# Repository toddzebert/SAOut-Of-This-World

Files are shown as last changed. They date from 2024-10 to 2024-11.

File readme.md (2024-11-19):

# SAOut Of This World

Originally intended for the [2024 Supercon SAO Contest] (https://hackaday.com/tag/2024-supercon-sao-contest/) but we missed the deadline. Wha wha. We'll be introducing it at Supercon 2024 in early November in Pasadena, CA.

A koppanyh and Todd Zebert production. 
 
Copyright (c) 2024 koppanyh & Todd Zebert, under a modified MIT license.

Kop handled the PCB design and art, with a bit of input from Todd, while Todd was working on the code bouncing ideas off of Kop.

## Features

Besides being out of this world in design and fairly LED-y, it works as an i2c target device to both select different "effects" or assume complete control of the 5 LEDs and 16 WS2812s. Two LEDs are wired to in a special "sensing" circuit. It also features two buttons.

## Usage

The left button sequences between "Effects" for the Upper Trim (the 5 WS2812's in the middle), while the right button sequences between Effects for the Lower Trim (WS2812's at the bottom).

A long press on the left button will enter "brightness control mode" - the left eye will go into a rapid red flashing to indicate such. Subsequent regular (short) button presses on left or right, will decrease or increase, respectively, brightness. Use a left long press to return to normal mode.

## Todo's

* Create hackaday.io project 
* see [Firmware readme](firmware/readme.md)

## Board Previews.

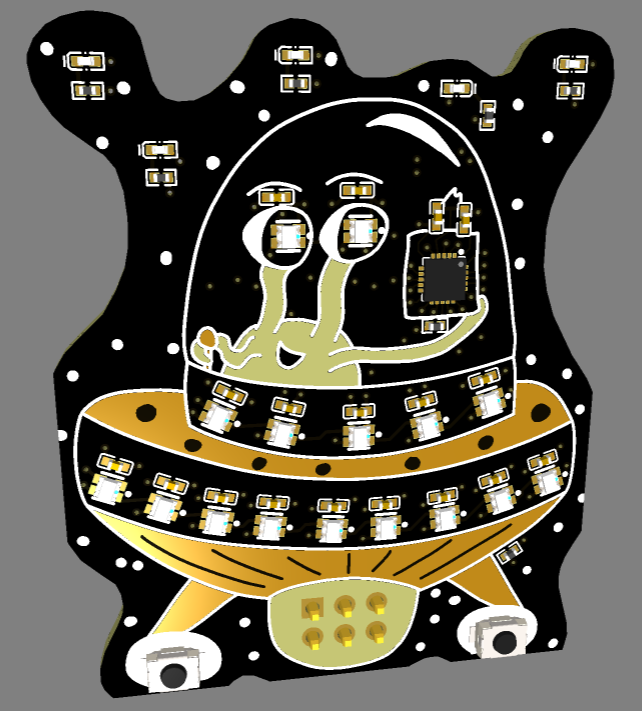
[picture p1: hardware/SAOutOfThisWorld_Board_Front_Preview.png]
SAOut Of This World Front Preview

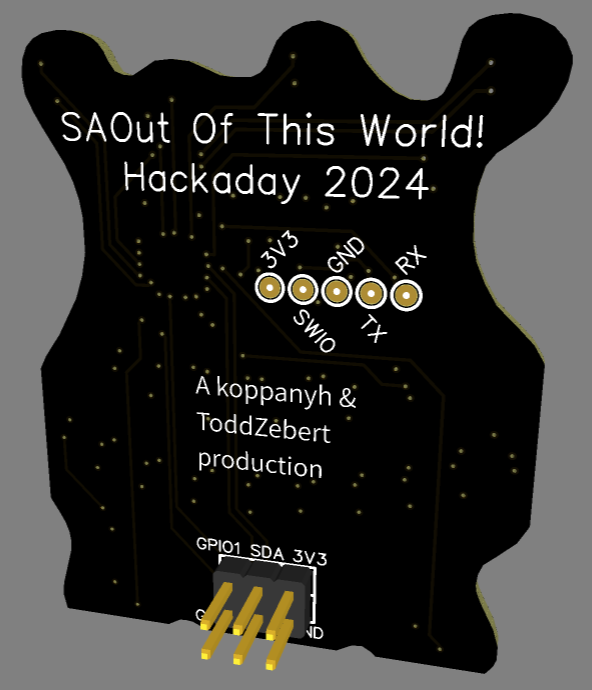
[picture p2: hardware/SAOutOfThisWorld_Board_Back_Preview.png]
SAOut Of This World Back Preview


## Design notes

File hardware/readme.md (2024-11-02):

# Hardware

## Ports, Usages, Pins, etc.

| Port | Usage | Pin | Notes |
|---|---|-----|---|
| NRST | GND |  1  | |
| PA1 | SenseLED1+ |  2  | *A1 |
| PA2 | GLED3 |  3  | *A0 |
| VSS | GND |  4  | |
| PD0 | GLED2 |  5  | *Non-A |
| VDD | VCC |  6  | |
| PC0 | GLED1 |  7  | *Non-A |
| SDA | SDA |  8  | PC1 |
| SCL | SCL |  9  | PC2 |
| PC3 | Button1 | 10  | to GND, Pull-up |
| PC4 | Button2 | 11  | to GND, Pull-up |
| PC5 | SAO GPIO2  | 12  | |
| MOSI | Neopixel | 13  | PC6 |
| PC7 | SAO GPIO1  | 14  | |
| SWIO | SWIO | 15  | PD1, Programer, exp. pad |
| PD2 | SenseLED2- | 16  | *A3 |
| PD3 | SenseLED2+ | 17  | *A4 |
| PD4 | SenseLED1- | 18  | *A7 |
| UTX | UTX | 19  | PD5, USART, exposed pad  |
| URX | URX | 20  | PD6, USART, exposed pad  |
| VSS | GND | 21  | |

## Sense LEDs

Two LEDs are both sunk and sourced by the MCU so it can run both in forward and reverse bias (sensing) modes. 

## CH32 Product line part number notes
In case you were curious, Ex: CH32V003F4U6

- CH32 = product line.
- V = QingKe RISC-V-based
- 0 = QingKe V2 core (no FP)
- 03 = General Purpose
- F = 20 pins
- 4 = 16 Kbytes of Flash memory 
- P/U = TSSOP/QFN respectively
- 6 = -40℃～85℃ (industrial-grade)

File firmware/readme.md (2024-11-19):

# Firmware for SAOut Of This World

## Setup
1) Install VSCode
2) Install the PlatformIO extension in VSCode
3) Clone the [ch32v003fun](https://github.com/cnlohr/ch32v003fun) repo
4) Follow the [installation](https://github.com/cnlohr/ch32v003fun/wiki/Installation) guide
5) Open it with PlatformIO and let it set up
6) Open the SAOut Of This World firmware project with PlatformIO
7) Let it set up, then click Build to see if it worked

# Description

At its core, its a synchronous finite state machine; it's not (directly) event-driven, because events are "buffered" into the synchronous tock of the main loop. It more or less follows the [UML state machine](https://en.wikipedia.org/wiki/UML_state_machine). It's written in straight C.

It uses the [ch32v003fun](https://github.com/cnlohr/ch32v003fun) "environment" to avoid the manufacturer's weighty HAL/EVT; the community around it has been very helpful. We also use PlatformIO to build the project.

Conceptually, initially an init Event is passed to each Thing. Then there's the main loop, which communicates with Things. There are two types of Things: input and output. Output Things (like Stars,Eyes, Trim) are associated with and communicate with Effects (like Twinkle, Blink, Rotate). Input Things (like Buttons, GPIO) do not have associated Effects.

Effects each have a timer, based on tocks, associated with a Thing. When the timer expires, a Run Event is passed to each Thing which in turn passes on the event to the Effect. Other input events are passed similarly via the main loop.

Another way of thinking about it is kinda like PubSub, but Things don't have to "subscribe", we "publish" all events to all Things (then passed on to Effects). Currently, Effects return a "dirty" flag, which is then returned by the corresponding Thing, to alert the main loop that the WS2812s need to be updated.

Other input events include i2c writes, (SAO) GPIO inputs, buttons and the "sense" LEDs. Most are "polled" with the exception of the i2c writes (handled by an ISR). Polled Things return an Event, to be processed in the main loop. The i2c is unique and isn't really a Thing; it "sends" Events by setting a "Global Event" var which again, is processed in the main loop. 

While both Things and Effects maintain there own UML "action" state (ENTER, GO, EXIT, etc), as do "output" Things, but so far there's no need for "output" Things to do so. Things and Effects also maintain their own internal state, as needed.

The next most important concept is the "registry". Because this SAO is meant to be an i2c target, all the settings and outputs are stored in the registry. The i2c library modifies the registry directly when it receives a write. Things and Effects depend on both reading and writing to the registry. Any i2c controller can switch Effect "modes", settings, or even control the LEDs and WS2812s directly using the "Raw" Effect.

For Stars, the 8bit value is passed through a gamma map table, then its reduced to 6 bits for the LED soft PWM.

The MCU is the CH32V003F4U6 (QFN-20) chip, with 2 buttons, 16 WS2812s (in one channel) and five (soft PWM)LEDs, two of which are wired special - see the hardware readme.

When tested during supercon 2024, it was pulling high 30's to mid 40's ma.

## Tock

`SysClick` is used to create a synchronous 1ms "tock". The main loop runs on the tocks.

## i2c Use
@todo
* I2C_ADDRESS 0x09

## Libraries (/lib)
* Color Utilities
* i2c_slave
  * Modified from example - thanks [true] - to:
    * better handle errors, especially stop.
    * Not call callbacks when i2c IDs don't match.
    * Increase priority.
* rand
* ws2812b_dma_spi_led_driver

## TODO & Progress

* [In progress] Finish & test i2c. Probably need a "dirty" reg entry - nope, write callback can determine.
* [Emit done, queue added, thing "listeners" some done] Things' (input) events and actions.
* Enhance and add Effects (perhaps "pallets" in each effect>)
* Review GH Issue.
* [Hold] Sense LEDs

## Change Log

* [Done] Global "mode" visual indications, perhaps eyes?
* [Done] brightness control.
* [Done] Fix Comet effect
* [Done] make Twinkle fade-in/fade-out.
* [Done] Buttons
* [Done] Events base code
* [Done] Fix "PA" GPIO pins - thanks Discord
* [Done] reduce GPIO speeds
* [Done] fix i2c crashing - thanks [true]
* [Done] Make LEDs (soft) PWM - thanks [true]
  
## Future ideas

* The mismatch of the length of `enum Things_t` and arrays such as `reg_thing_start[]` could be an issue in the future.
* Right now Things and Effects return `dirty` to alert the main loop that the WS' need to be updated, and timing intervals (delays) are set in a global var. I'd like to uncouple that so they return a struct with both dirty and delay, and maybe more. I want to avoid putting too much on the stack though, although I suspect the call stack is never more than a few calls deep: Main Loop, Thing, Effect handler, Effect State handler, and perhaps a helper routine. There's no recursion.
* Twinkle effect: add normally on and normally off modes.
* Add the "CC3K" effect.
* Move i2c stuff from main to its own file, and DRY out `main()` including the main loop.

## CH32V003FUN Platform Notes

* To get a random binary: `rnd_fun(0, 1) & 0x01)`
* To get a 0-255 randomly: `(uint8_t)rnd_fun(0, 1)`
* It does not support `malloc`.
* For best RISC performance, focus on 0's in loops/counters.
* The i2c_slave/src/i2c_slave.h is modified from the fun example's version to clear stop condition on error, and increase IRQ priority.
* Do not use `Delay_Ms()` as it is incompatible with 

## Thanks.
Special thanks to cnlohr for the [ch32v003fun](https://github.com/cnlohr/ch32v003fun) project,
and all the helpful people on his Discord server. And to [true] at the Hackaday Supercon 2024.

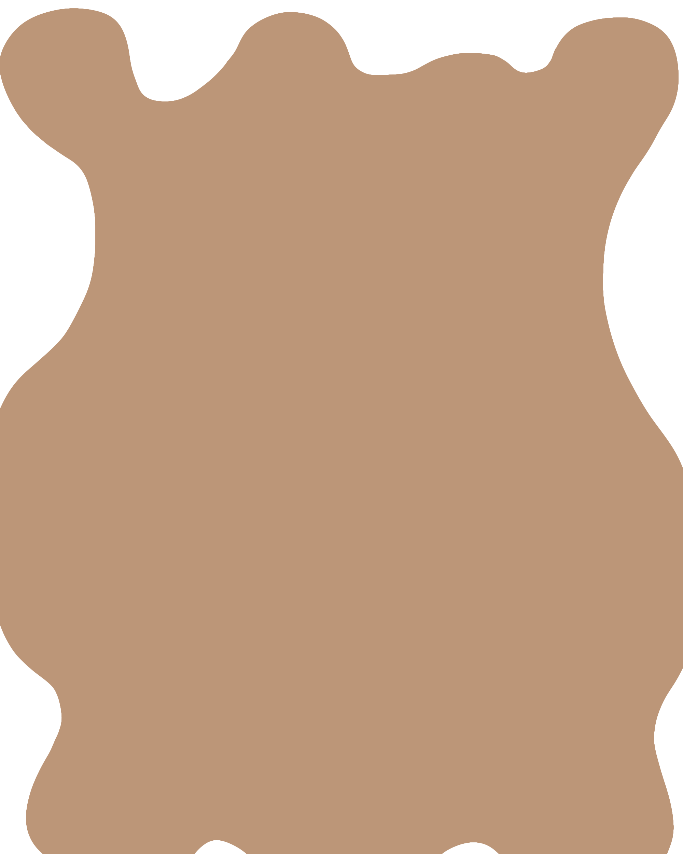
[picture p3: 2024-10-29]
hardware/pcb_layers/board.png

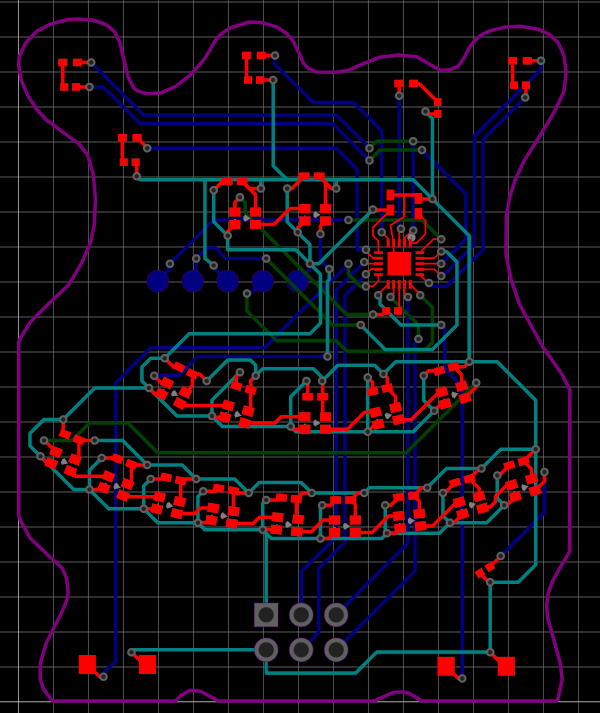
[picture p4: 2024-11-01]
hardware/SAOutOfThisWorld_Board_Traces.png

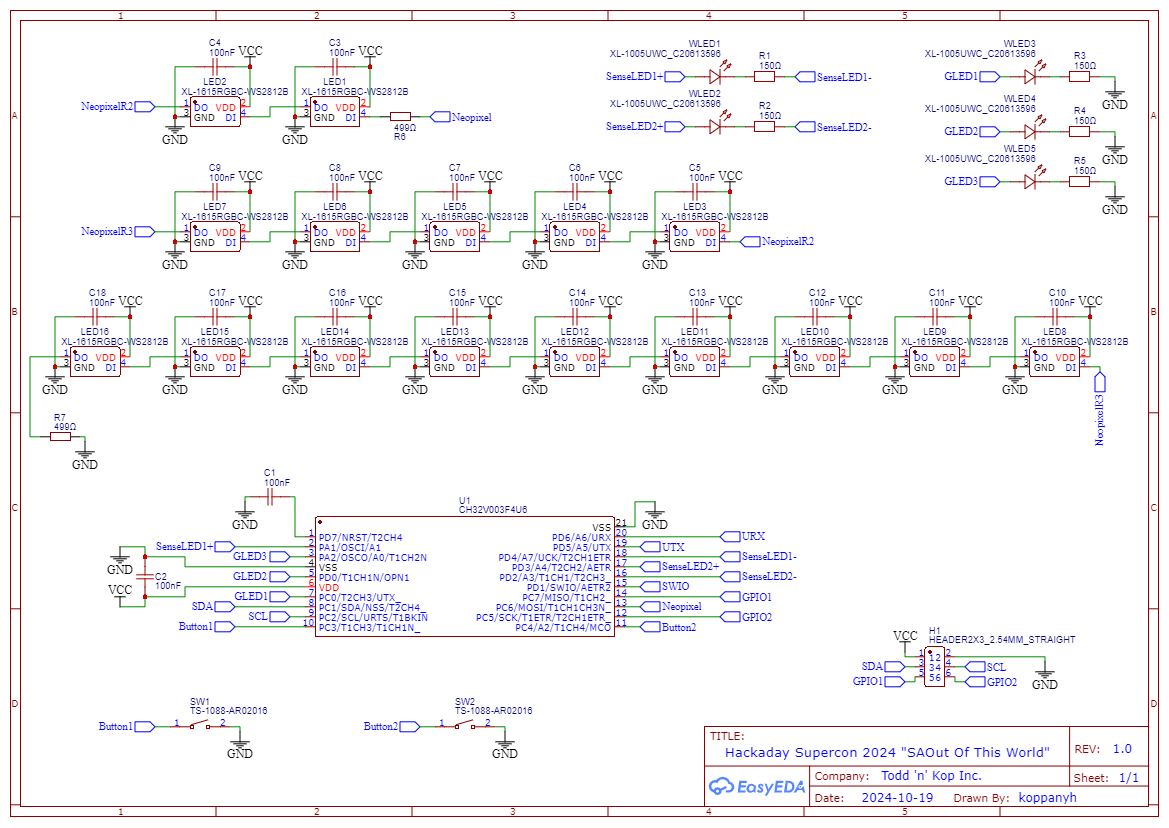
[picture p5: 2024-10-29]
hardware/Schematic_HD2024SAO.png

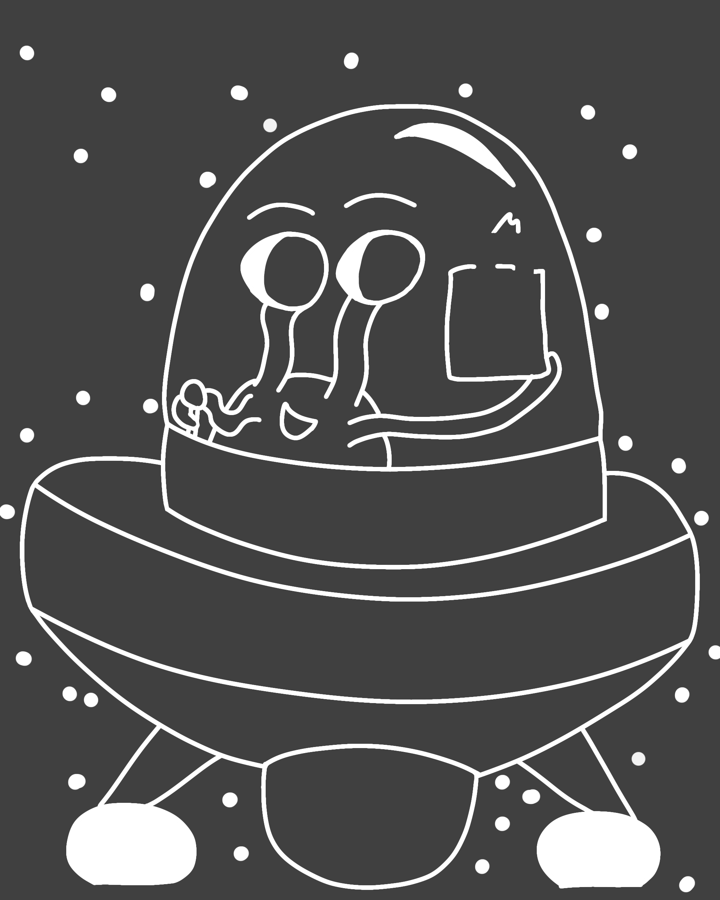
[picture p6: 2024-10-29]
hardware/pcb_layers/silkscreen.png

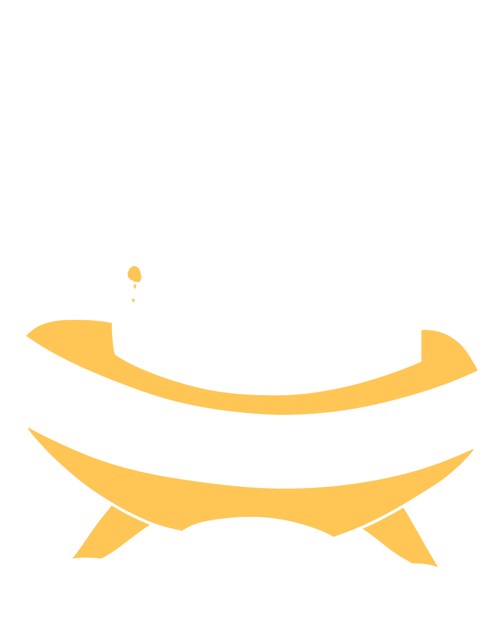
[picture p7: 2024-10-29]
hardware/pcb_layers/copper.png

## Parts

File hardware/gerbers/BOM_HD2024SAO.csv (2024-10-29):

ID | Name | Designator | Footprint | Quantity | Manufacturer Part | Manufacturer | Supplier | Supplier Part | Price
1 | TESTPOINT_1MM5 | 3V3,SWIO,GND,TX,RX | TESTPOINT_1MM5 | 5
2 | HEADER2X3_2.54MM_STRAIGHT | H1 | HDR-TH_6P-P2.54-V-M-R2-C3-S2.54 | 1 | X6521WV-2×03H-C30D60 | XKB Connectivity | LCSC | C706893 | 0.09
3 | 100nF | C1,C2,C3,C4,C5,C6,C7,C8,C9,C10,C11,C12,C13,C14,C15,C16,C17,C18 | C0402 | 18 | CC0402KRX7R7BB104 | YAGEO(国巨) | LCSC | C60474 | 0.001
4 | XL-1615RGBC-WS2812B | LED1,LED2,LED3,LED4,LED5,LED6,LED7,LED8,LED9,LED10,LED11,LED12,LED13,LED14,LED15,LED16 | LED-SMD_4P-L1.6-W1.5_XL-1615RGBC-WS2812B | 16 | XL-1615RGBC-WS2812B | XINGLIGHT(成兴光) | LCSC | C5349954 | 0.046
5 | 150Ω | R1,R2,R3,R4,R5 | R0402 | 5 | ERJ2RKF1500X | PANASONIC(松下) | LCSC | C413067 | 0.005
6 | 499Ω | R6,R7 | R0402 | 2 | 0402WGF4990TCE | UNI-ROYAL(厚声) | LCSC | C4125 | 0.001
7 | TS-1088-AR02016 | SW1,SW2 | SW-SMD_L3.9-W3.0-P4.45 | 2 | TS-1088-AR02016 | XUNPU(讯普) | LCSC | C720477 | 0.041
8 | CH32V003F4U6 | U1 | QFN-20_L3.0-W3.0-P0.40-TL-EP1.7 | 1 | CH32V003F4U6 | WCH(南京沁恒) | LCSC | C5299908 | 0.249
9 | XL-1005UWC_C20613596 | WLED1,WLED2,WLED3,WLED4,WLED5 | LED0402-RD_YELLOW | 5 | XL-1005UWC | XINGLIGHT(成兴光) | LCSC | C20613596 | 0.009

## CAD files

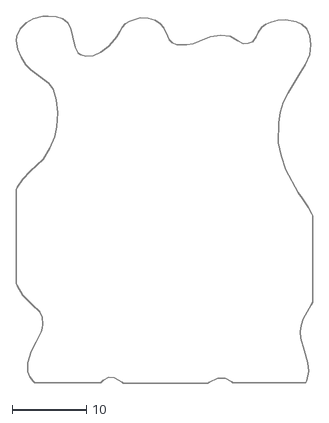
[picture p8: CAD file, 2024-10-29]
hardware/pcb_layers/board.dxf
40.0 x 49.5

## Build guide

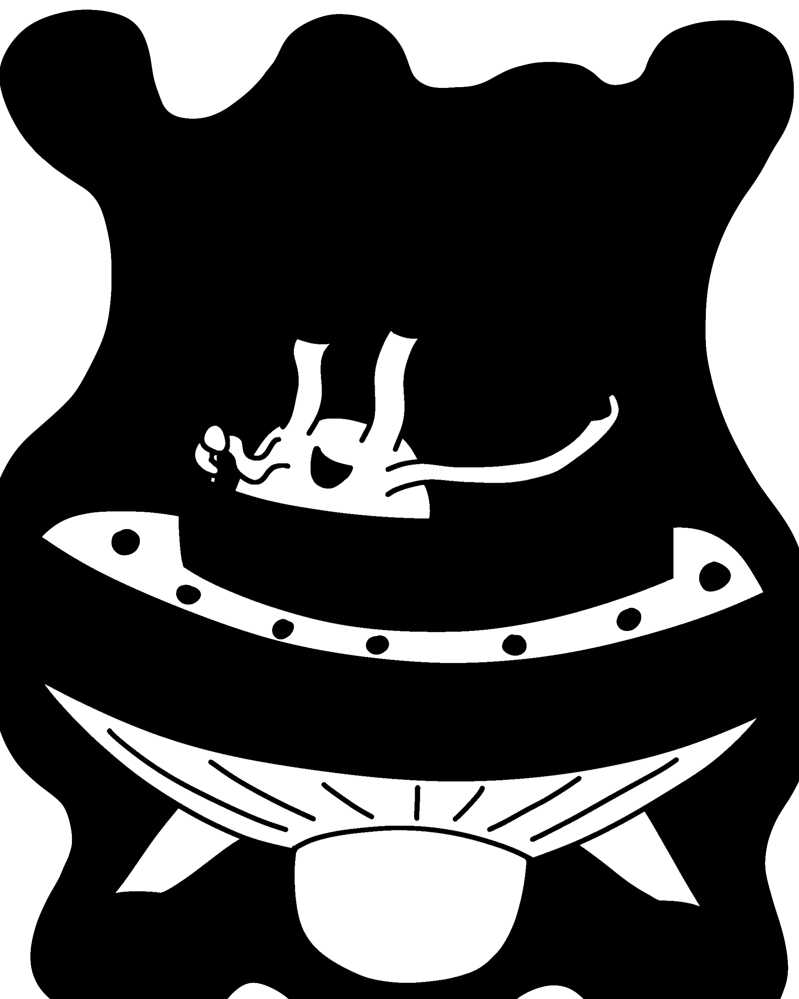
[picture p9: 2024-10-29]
hardware/pcb_layers/soldermask.png

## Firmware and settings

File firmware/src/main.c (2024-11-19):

/*
 * main.c
 *
*/

#include <rand.h> // @debug

/*
    From ws2812b_dma_spi_led_driver.h:
        void DMA1_Channel3_IRQHandler( void );

    Timer1 is used for Stars PWM.
*/

/*
The I2C (inter-IC) bus can transfer data at different speeds, including: 
    Standard mode: 100 kbit/s 
    Fast mode: 400 kbit/s 
    Fast mode plus: 1 Mbit/s 
    High-speed mode: 3.4 Mbit/s 
    Ultra-fast mode: 5 Mbit/s 
*/

#include "main.h"

// Timers.
volatile uint8_t timer_tock = 0;

// I2C.
#define I2C_ADDRESS 0x09

// Reserved registers. Meant to be R/O but the lib doesn't support it, so this is the backup copy.
#define REG_RESERVED_RO_LENGTH 2 // Up to 16 avail.

const uint8_t reg_reserved_ro[REG_RESERVED_RO_LENGTH] = {
    0, // API Major version,
    3, // API Minor version
};

struct {
    uint8_t Brightness_mode: 1;
} Global_state = {
    .Brightness_mode = 0
};

#define BRIGHTNESS_MODE_DISABLED 0
#define BRIGHTNESS_MODE_ENABLED 1

#define GLOBAL_RETURN_NONE 0
#define GLOBAL_RETURN_STOP_PROP 1

/**
 * @brief Initializes the SysTick counter to fire once per millisecond.
 *
 * Resets any pre-existing configuration, sets the compare register to trigger
 * once per millisecond, resets the Count Register, sets the SysTick
 * configuration, and enables the SysTick IRQ.
 *
 * @note This is a modified version of the example
 *       <https://github.com/cnlohr/ch32v003fun/blob/master/examples/systick_irq/systick_irq.c>.
 */
void systick_init(void)
{
	// Reset any pre-existing configuration
	SysTick->CTLR = 0x0000;
	
	// Set the compare register to trigger once per millisecond
	SysTick->CMP = SYSTICK_ONE_MILLISECOND - 1;

	// Reset the Count Register.
	SysTick->CNT = 0x00000000;
	
	// Set the SysTick Configuration
	// NOTE: By not setting SYSTICK_CTLR_STRE, we maintain compatibility with
	// busywait delay funtions used by ch32v003_fun.
	SysTick->CTLR |= SYSTICK_CTLR_STE   |  // Enable Counter
	                 SYSTICK_CTLR_STIE  |  // Enable Interrupts
	                 SYSTICK_CTLR_STCLK |  // Set Clock Source to HCLK/1
                     SYSTICK_CTLR_STRE;    // Enable Auto Reload
    
	
	// Enable the SysTick IRQ
	NVIC_SetPriority(SysTicK_IRQn, 2 << 6);
    NVIC_EnableIRQ(SysTicK_IRQn);
}


void SysTick_Handler(void) __attribute__((interrupt));
/**
 * @brief Interrupt Service Routine for SysTick timer.
 *
 * This function handles the SysTick interrupt, which occurs every 1ms. 
 * It sets the `timer_tock` flag to indicate the timer tick has occurred
 * and clears the SysTick status register to reset the interrupt trigger state.
 * 
 * Tocks are 1ms.
 */
void SysTick_Handler(void)
{
    timer_tock = 1;

	// Clear the trigger state for the next IRQ
	SysTick->SR = 0x00000000;
}


void copyInRegReservedGlobal()
{
    // @todo future use?
}

/**
 * @brief Copy the "read-only" registry values from the reserved constants to the actual registry.
 *
 * While it's intended to be called once at startup, it'll be called again if the registry is changed.
 *
 * @note This function exists since the lib doesn't support R/O registers.
 */
void copyInRegReservedRO()
{
    constToRegCopy(registry, 0, reg_reserved_ro, 0, sizeof(reg_reserved_ro) * sizeof(uint8_t));
}


/**
 * @brief Called when a write is received over I2C, with values altered in registry.
 * 
 * @param[in] reg The register address written to.
 * @param[in] length The number of bytes written.
 * 
 * @note This is a callback function and is not intended to be called directly.
 * @todo Check protected "RO" registers and replace.
 */
void onI2cWrite(uint8_t reg, uint8_t length) {
    // printf("onI2cWrite(%d, %d)\n", reg, length); // @debug

    // Check protected "RO" registers and replace with our settings.
    // @debug untested.
    if (reg < REG_RESERVED_RO_LENGTH) copyInRegReservedRO();

    Event_t reg_change_event = {
        .type = EVENT_REG_CHANGE,
        .thing = THING_ALL,
        .data.reg_change.reg = reg,
        .data.reg_change.length = length
    };

    eventPush(reg_change_event);
}


/**
 * @brief Called when a read is requested over I2C from the registry, but is only an "alert".
 * 
 * @param[in] reg The register address read from.
 * 
 * @note This is a callback function and is not intended to be called directly.
 * @todo Check if we need to do anything here.
 */
void onI2cRead(uint8_t reg) {
    // @todo ?
}


/**
 * @brief Initializes the I2C slave interface.
 *
 * Initializes the I2C slave interface pins (SDA and SCL) and sets up the I2C slave
 * using the i2c_slave library. The I2C address is set to I2C_ADDRESS, the registry
 * is set to the registry array of length sizeof(registry), and the onI2cWrite and
 * onI2cRead callback functions are set.
 *
 * @note This function is intended to be called once, at initialization time.
 */
void init_i2c() {
    // i2c_slave.
    funPinMode(PC1, GPIO_CFGLR_OUT_2Mhz_AF_OD); // SDA // @debug was GPIO_CFGLR_OUT_10Mhz_AF_OD.
    funPinMode(PC2, GPIO_CFGLR_OUT_2Mhz_AF_OD); // SCL // @debug was GPIO_CFGLR_OUT_10Mhz_AF_OD.

    SetupI2CSlave(I2C_ADDRESS, registry, sizeof(registry), onI2cWrite, onI2cRead, false);
}


/**
 * @brief The global event handler.
 *
 * This function is responsible for handling Global events that are not specific to
 * a specific Things. If the event is a button press, it will handle it if the global
 * brightness mode is enabled. If the brightness mode is disabled, it will
 * ignore the event.
 *
 * @param[in] event The event to handle.
 * @return The return value is one of the GLOBAL_RETURN_* constants. If
 * GLOBAL_RETURN_STOP_PROP is returned, the event will not be propagated to
 * other handlers. If GLOBAL_RETURN_NONE is returned, the event will be
 * propagated to other handlers.
 */
int globalHandler(Event_t event)
{
    switch (event.type)
    {
        case EVENT_BUTTON:
            // First handle long press.
            if (event.data.button.type == BUTTON_LONG_PRESSED)
            {
                // Check which button.
                if (event.data.button.num == BUTTON_RIGHT)
                {
                    // Silce if in mode, otherwise pass.
                    if (Global_state.Brightness_mode == BRIGHTNESS_MODE_ENABLED)
                        return GLOBAL_RETURN_STOP_PROP;
                    else
                        return GLOBAL_RETURN_NONE;
                }
                else
                {
                    // Must be left button.
                    if (Global_state.Brightness_mode == BRIGHTNESS_MODE_ENABLED)
                    {
                        // Disable brightness mode.
                        Global_state.Brightness_mode = BRIGHTNESS_MODE_DISABLED;

                        Event_t Event_global = {
                            .type = EVENT_GLOBAL,
                            .thing = THING_ALL,
                            .data = {
                                .global = {
                                    .mode = GLOBAL_MODE_BRIGHTNESS,
                                    .state = 0
                                }
                            }
                        };

                        eventPush(Event_global);
                        
                        // Even though mode is disabled, eat the button that caused it.
                        return GLOBAL_RETURN_STOP_PROP;
                    }
                    else
                    {
                        // Enable brightness mode.
                        Global_state.Brightness_mode = BRIGHTNESS_MODE_ENABLED;

                        Event_t Event_global = {
                            .type = EVENT_GLOBAL,
                            .thing = THING_ALL,
                            .data = {
                                .global = {
                                    .mode = GLOBAL_MODE_BRIGHTNESS,
                                    .state = 1
                                }
                            }
                        };

                        eventPush(Event_global);

                        return GLOBAL_RETURN_STOP_PROP;
                    }
                    
                }
            }
            // Now handle regular presses.
            else if (event.data.button.type == BUTTON_PRESSED)
            {
                if (Global_state.Brightness_mode == BRIGHTNESS_MODE_DISABLED)
                    return GLOBAL_RETURN_NONE;

                // OK, time to change brightness.
                if (event.data.button.num == BUTTON_LEFT)
                {
                    if (registry[REG_GLOBAL_BRIGHTNESS] > 0)
                        registry[REG_GLOBAL_BRIGHTNESS]--;

                    return GLOBAL_RETURN_STOP_PROP;
                }
                else if (event.data.button.num == BUTTON_RIGHT)
                {
                    if (registry[REG_GLOBAL_BRIGHTNESS] < 8)
                        registry[REG_GLOBAL_BRIGHTNESS]++;

                    return GLOBAL_RETURN_STOP_PROP;
                }
            }
            
            break;

        default:
            break;
    }

    return GLOBAL_RETURN_NONE;
}

/**
 * @brief Main entry point.
 * 
 * @details
 * This is the main entry point for the program. It initializes all the
 * peripherals and starts the main loop.
 * 
 * The main loop is an infinite loop that checks for button presses and
 * updates the LEDs accordingly. It also handles the WS2812B LEDs and makes
 * sure that the LEDs are updated when needed.
 * 
 * @note This function does not return.
 */
int main()
{
	SystemInit();

    init_i2c();

    copyInRegReservedRO();

    copyInRegReservedGlobal();

    funGpioInitAll();
    // @debug testing this.  From PA's issue.... probably no longer needed.
    RCC->APB2PCENR |= RCC_AFIOEN;
    //Delay_Ms(1);
    AFIO->PCFR1 &= ~AFIO_PCFR1_PA12_REMAP;

    // Init "things".
    const Event_t Event_Init = {
        .type = EVENT_INIT,
        .thing = THING_ALL
    };

     // @todo All the things inits should be done more dynamically.
    buttonHandler(Event_Init);
    eyesHandler(Event_Init);
    starsHandler(Event_Init);
    upperTrimHandler(Event_Init);
    lowerTrimHandler(Event_Init);

    // WS2812 init and initial "start" to render. Must go after all "things" inits, ...Handler(1)'s.
    WS2812_Init();

    // Prep for main loop.
    int ws_dirty = 0;

    const Event_t Event_Run = {
        .type = EVENT_RUN,
        .thing = THING_ALL
    };

    Delay_Ms(500); // @debug

    // printf("in main, size of Event_t: %d\n", sizeof(Event_t)); // @debug

    // for (int i = 0; i < 10; i++) printf("rand 0|1: %d\n", rnd_fun(0, 1) & 0x01); // @debug

    systick_init();

    printf("In main, right before loop.\n"); // @debug

    while(1)
    {
        if (timer_tock)
        {
            timer_tock = 0;

            // Use of this should be limited as its expensive.
            while (!eventQueueEmpty())
            {
                // printf("in main event while loop.\n"); // @debug
                Event_t event = eventPop();
                printf("In main loop event while - type, thing: %d %d\n", event.type, event.thing); // @debug

                // Global gets priority, and return here is not dirty, but a return state.
                if (globalHandler(event) == GLOBAL_RETURN_STOP_PROP) continue;

                buttonHandler(event); // @todo can we think of a reason for this?

                ws_dirty = eyesHandler(event) || ws_dirty;
                ws_dirty = starsHandler(event) || ws_dirty;
                ws_dirty = upperTrimHandler(event) || ws_dirty;
                ws_dirty = lowerTrimHandler(event) || ws_dirty;
            }

            // Handle buttons.
            thing_tock_timer[THING_BUTTONS]--;
            if ( thing_tock_timer[THING_BUTTONS] == 0 ) {
                // @todo Also, perhaps this should go higher in the loop so the event can be processed
                // as part of the existing global event handling conditional.
                buttonHandler(Event_Run);
            }

            // Handle Eyes.
            thing_tock_timer[THING_EYES]--;
            if ( thing_tock_timer[THING_EYES] == 0 )
            {
                ws_dirty = eyesHandler(Event_Run) || ws_dirty;
            }

            // Handle Upper Trim.
            thing_tock_timer[THING_UPPER_TRIM]--;
            if ( thing_tock_timer[THING_UPPER_TRIM] == 0 )
            {
                ws_dirty = upperTrimHandler(Event_Run) || ws_dirty;
            }

            // Handle Lower Trim.
            thing_tock_timer[THING_LOWER_TRIM]--;
            if ( thing_tock_timer[THING_LOWER_TRIM] == 0 )
            {
                ws_dirty = lowerTrimHandler(Event_Run) || ws_dirty;
            }

            // This should always be at the end, after all WS Things handlers.
            if (ws_dirty) {
                ws_dirty = 0;
                WS2812_Handler();
            }

            // Handle Stars (not a WS Thing).
            thing_tock_timer[THING_STARS]--;
            if ( thing_tock_timer[THING_STARS] == 0 )
            {
                starsHandler(Event_Run);
                // @note Stars updates (like dirty state) are handled by the PWM ISR.
            }
        }
    }

    __WFI(); // Wait for Interrupt.
}

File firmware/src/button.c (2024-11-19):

#include "button.h"
#include <stdio.h>

#include <ch32v003fun.h>

const uint8_t button_gpio_pins[BUTTON_NUM] = { PC3, PC4 };

// Timers and states for each of the buttons.
Button_State_t button_state[BUTTON_NUM];

void buttonHandler_run(Event_t event);

void buttonHandler(Event_t event)
{
    // printf( "In buttonHandler, event.type: %d\r\n", event.type ); // @debug
    if (!(event.thing == THING_BUTTONS || event.thing == THING_ALL))
        return;

    switch (event.type)
    {
        case EVENT_INIT:
            // printf( "In buttonHandler EVENT_INIT, event.type: %d\r\n", event.type ); // @debug
            for (int i = 0; i < BUTTON_NUM; i++)
            {
                funPinMode(button_gpio_pins[i], GPIO_CNF_IN_PUPD);
                funDigitalWrite(button_gpio_pins[i], FUN_HIGH);

                // Default vals.
                button_state[i].machine_state = BUTTON_SM_WAIT_FOR_START;
                button_state[i].debounced_state = false;
                button_state[i].press_count = 0;
                button_state[i].release_count = 0;
                button_state[i].hold_count = 0;

                state_action[THING_BUTTONS] = STATE_ACTION_ENTER;
                thing_tock_timer[THING_BUTTONS] = DEBOUNCE_TIMER_BASE;
            }
            break;

        case EVENT_RUN:
            buttonHandler_run(event);
            break;
        
        default:
            break;
    }

    return;
}

void buttonHandler_run(Event_t event)
{
    for (int i = 0; i < BUTTON_NUM; i++)
    {
        // Since we're using pull-ups, the state will be inverted.
        bool raw_state = !funDigitalRead(button_gpio_pins[i]);
        //printf("button %d: %d\r\n", i, raw_state); // @debug

        // Debounce the button.
        if (raw_state)
        {
            // We see the button is pressed, stop any released counting.
            button_state[i].release_count = 0;

            if (button_state[i].press_count < 255)
                button_state[i].press_count++;
            // If we have been pressed for N consecutive cycles and the
            // debounced state isn't true, then we flip the state.
            if (
                button_state[i].press_count >= DEBOUNCE_DELAY_COUNT &&
                !button_state[i].debounced_state
            ) button_state[i].debounced_state = true;
        }
        else
        {
            // We see the button is not pressed, stop any pressed counting.
            button_state[i].press_count = 0;

            if (button_state[i].release_count < 255)
                button_state[i].release_count++;
            // If we have been released for N consecutive cycles and the
            // debounced state is true, then we flip the state.
            if (
                button_state[i].release_count >= DEBOUNCE_DELAY_COUNT &&
                button_state[i].debounced_state
            ) button_state[i].debounced_state = false;
        }

        // External event that tells us what the button is doing.
        Button_Event_Type_t button_event_type = BUTTON_NONE;

        // Detect events for click/long/double.
        bool debounced_state = button_state[i].debounced_state;
        
        if (button_state[i].machine_state == BUTTON_SM_WAIT_FOR_START)
        {
            if (debounced_state)
            {
                button_state[i].hold_count = 0;
                //printf("BUTTON_SM_WAIT_FOR_START -> BUTTON_SM_COUNT_LONG_PRESS\n");
                button_state[i].machine_state = BUTTON_SM_COUNT_LONG_PRESS;
            }
        }

        if (button_state[i].machine_state == BUTTON_SM_COUNT_LONG_PRESS)
        {
            if (debounced_state)
            {
                button_state[i].hold_count++;

                if (button_state[i].hold_count == LONG_PRESS_DELAY_COUNT)
                {
                    button_event_type = BUTTON_LONG_PRESSED;
                    //printf("BUTTON_SM_COUNT_LONG_PRESS -> BUTTON_SM_WAIT_FOR_STOP\n");
                    button_state[i].machine_state = BUTTON_SM_WAIT_FOR_STOP;
                }
            }
            else
            {
                button_state[i].hold_count = 0;
                //printf("BUTTON_SM_COUNT_LONG_PRESS -> BUTTON_SM_COUNT_DOUBLE_PRESS\n");
                button_state[i].machine_state = BUTTON_SM_COUNT_DOUBLE_PRESS;
            }
        }

        if (button_state[i].machine_state == BUTTON_SM_COUNT_DOUBLE_PRESS)
        {
            if (!debounced_state)
            {
                button_state[i].hold_count++;

                if (button_state[i].hold_count == DOUBLE_PRESS_DELAY_COUNT)
                {
                    button_event_type = BUTTON_PRESSED;
                    //printf("BUTTON_SM_COUNT_DOUBLE_PRESS -> BUTTON_SM_WAIT_FOR_START\n");
                    button_state[i].machine_state = BUTTON_SM_WAIT_FOR_START;
                }
            }
            else
            {
                button_event_type = BUTTON_DOUBLE_PRESSED;
                //printf("BUTTON_SM_COUNT_DOUBLE_PRESS -> BUTTON_SM_WAIT_FOR_STOP\n");
                button_state[i].machine_state = BUTTON_SM_WAIT_FOR_STOP;
            }
        }

        if (button_state[i].machine_state == BUTTON_SM_WAIT_FOR_STOP)
        {
            if (!debounced_state)
            {
                //printf("BUTTON_SM_WAIT_FOR_STOP -> BUTTON_SM_WAIT_FOR_START\n");
                button_state[i].machine_state = BUTTON_SM_WAIT_FOR_START;
            }
        }

        if (button_event_type == BUTTON_NONE)
            continue;

        Event_t Event_Button = {
            .type = EVENT_BUTTON,
            .thing = THING_ALL,
            .data = {
                .button = {
                    .num = i,
                    .type = button_event_type
                }
            }
        };

        if (!eventQueueFull()) // @todo this conditional unnecessary - see eventPush().
            eventPush(Event_Button);

        /* Print it out just for debug.
        printf("buttonHandler_run (%d): ", i);
        switch (button_event_type)
        {
            case BUTTON_PRESSED:
                printf("Press event!\n");
                break;
            case BUTTON_LONG_PRESSED:
                printf("Long press event!\n");
                break;
            case BUTTON_DOUBLE_PRESSED:
                printf("Double press event!\n");
                break;
            default:
                printf("?\n");
                break;
        } // */
    }

    thing_tock_timer[THING_BUTTONS] = DEBOUNCE_TIMER_BASE;
    return;
}

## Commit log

2024-09-01 enable and configure UARTPRINTF - need RX TX from programmer to board
2024-09-01 add GPIO support, enable button pin, alter comet code for testing/demo, add button debounce code (needs work), some code cleanup, add comments
2024-09-01 revised i2c_slave lib dir
2024-09-01 add i2c slave stub code; device remains working
2024-09-04 Initial files for PCB art
2024-09-24 refactored main loop to get dirty from thing handler, made thing handlers take a init/run flag, and fixed eyes and blink
    [global.h, main.c]
2024-09-26 added thing stars; added effect twinkle; moved ws2812b support code to own file, fixed rand lib issue, added gitignore, plus misc fixes and improvements
    [global.h, main.c, stars.c]
2024-09-28 continued comet work (still WIP), modernized blink, removed non-fun GPIO lib, and converted button (but very WIP), code cleanup, comments, misc.
2024-10-20 Add PCB art layers
    [board.dxf]
2024-10-20 Added Gerbers and BOM and schematic
    [BOM_HD2024SAO.csv, PickAndPlace_PCB_HD2024SAO.csv]
2024-10-29 correctly implement systick irq
    [main.c]
2024-10-31 baseline Event code in place, i2c writes emit events - yet unhandled, lots of WIP on buttons/debounce - there seems to be a HW issue so disabled for now; misc tweaks.
    [button.c, global.h, main.c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]
2024-11-01 Upgrade to Real™ serial speed
2024-11-01 Add an image of the board traces for easier debug
2024-11-02 Implemented button debounce and gesture detection
2024-11-02 fixed i2c and made related changes
    [global.h, main.c]
2024-11-02 Refactor the button handler a little and write the events to the queue
2024-11-02 Fixed queue and made buttons rotate through effects
2024-11-03 complete rework of Stars LEDs for soft PWM, and misc related changes
    [global.h, main.c, stars.c]
2024-11-16 rewrite comet; fixed alpha application shared func; fixed button effect on trims; misc code cleanup, tweaks
    [global.h, main.c]
2024-11-18 add code to handle buttons to adjust brightness; some code cleanup; improve comments and docs
2024-11-19 fix sm bug in global handler button code
    [main.c]
2024-11-19 improve comments on stars soft PWM/ISR
